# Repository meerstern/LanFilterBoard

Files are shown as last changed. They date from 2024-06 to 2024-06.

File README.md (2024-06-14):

# LANフィルタ基板
LAN Filter Board

## 概要
 * 本基板はLANノイズフィルタの評価基板です  
 * LAN機器やケーブルから放射、伝搬されるノイズ、エミッションを低減させます
 * EMC試験やエミッション、伝導妨害試験等の対策検討に便利です  
 * Ethernet 100/1000BASE-Tに対応した360Ω@100MHzのコモンモードフィルタを実装しています  
 * 4ペアのコモンモードフィルタを実装しています  

## 使用方法
 * LAN機器のLANケーブル間に本フィルタを挿入して使用します   
 * 本フィルタはストレート結線です
 * ストレート結線のLANケーブルを使用してください
 * 4つのフィルタは基板に実装されているため、ハンダ付け不要です  
 
## 使用時の注意点
 * 本基板はフィルタの評価目的です  
 * 本基板を最終的な機器に組み込むことは想定していません  
 * 本基板はノイズ源に近い箇所に接続してください  
 * PoE環境での仕様は想定していません  
 * 使用方法によっては意図せず通信品質低下やエミッションが増加する場合があります  
 * 評価の際は本基板のエミッションを考慮した上で十分にシールドした状態で確認してください  
 * フィルタを含む表面実装部品に大きな力や衝撃を与えないように注意してください
 * 大きな力や衝撃によってフィルタが破損する場合があります  

## 詳細
 * 使用部品は下記です  
 * 告知なしに実装部品を後継品もしくは同等品に変更する場合があります  

| 部品 | 型式 | 仕様 | 
|:---|:---|:---|
| Port | [1149868][1] | Max 10 GBit/s |
| Filter | [ALC2012-361-2P-T00][2] | 360Ω@100MHz,DC 0.5Ω, Typ.220mA, [Link][3] |

## 外観
  * サイズ 約51mm x約30mm x約22mm(コネクタ含む) 
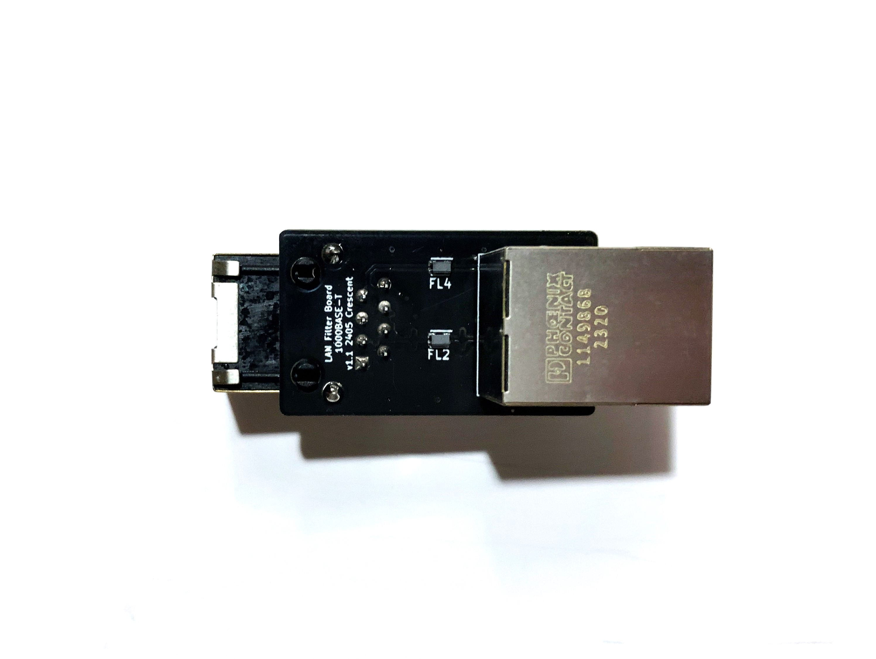
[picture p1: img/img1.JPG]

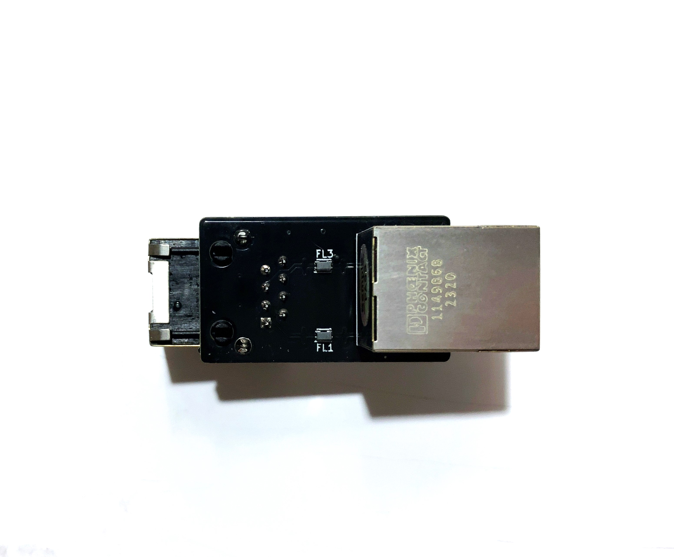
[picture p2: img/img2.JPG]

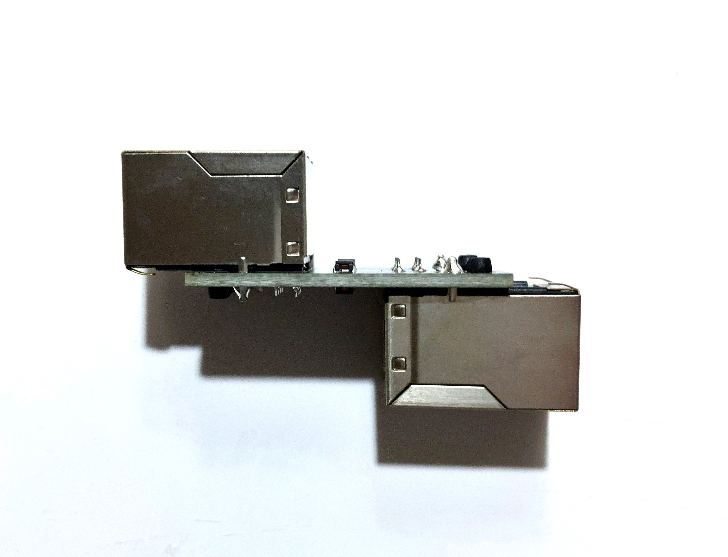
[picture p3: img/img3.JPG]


[1]: https://www.phoenixcontact.com/ja-jp/products/cuc-sp-j1st-a-r4lb-1149868
[2]: https://product.tdk.com/ja/search/emc/emc/cmf_cmc/info?part_no=ALC2012-361-2P-T00
[3]: https://product.tdk.com/ja/techlibrary/applicationnote/recommend_lan_cmf_cmc.html

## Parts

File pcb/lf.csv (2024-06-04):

ID | 参照記号 | パッケージ | 数 | 名称 | Supplier and ref
1 | FL4,FL3,FL2,FL1 | L_CommonModeChoke_Coilcraft_0805USB | 4 | EMI_Filter_CommonMode
2 | J2,J1 | 1149868 | 2 | 1149868

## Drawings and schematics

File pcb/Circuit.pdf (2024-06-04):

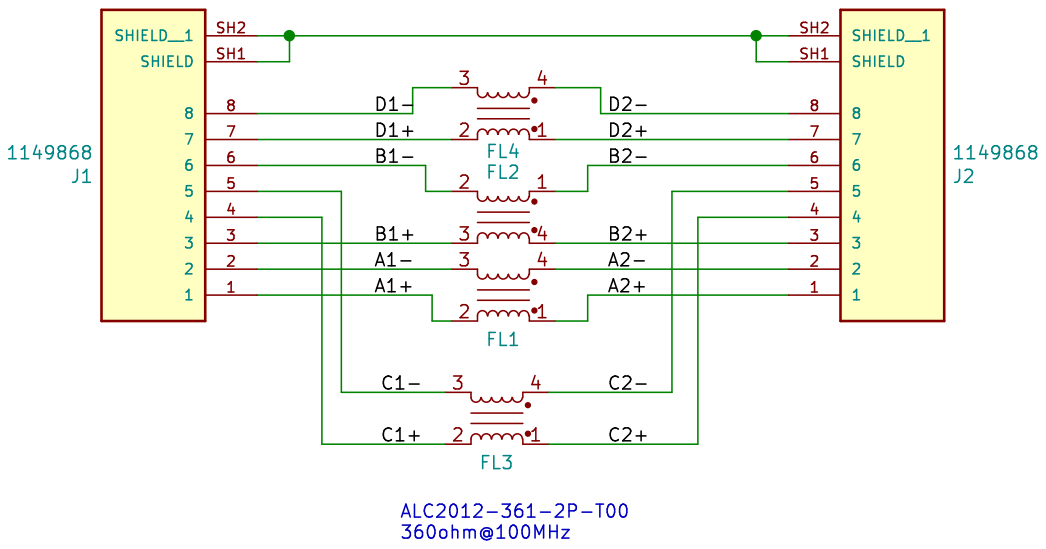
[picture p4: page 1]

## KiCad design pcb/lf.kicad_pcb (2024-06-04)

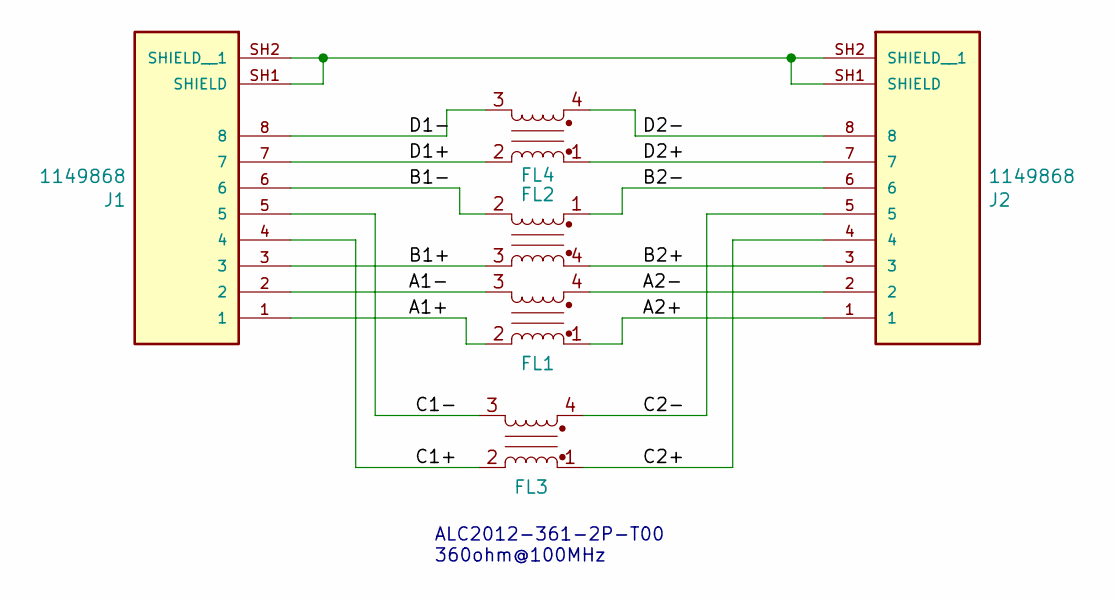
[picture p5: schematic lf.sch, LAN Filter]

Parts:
FL1, FL2, FL3, FL4: EMI_Filter_CommonMode; L_CommonModeChoke_Coilcraft_0805USB
J1, J2: 1149868; PARTREV 11.04.2022

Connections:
/A1+: FL1.2, J1.1
/A1-: FL1.3, J1.2
/A2+: FL1.1, J2.1
/A2-: FL1.4, J2.2
/B1+: FL2.3, J1.3
/B1-: FL2.2, J1.6
/B2+: FL2.4, J2.3
/B2-: FL2.1, J2.6
/C1+: FL3.2, J1.4
/C1-: FL3.3, J1.5
/C2+: FL3.1, J2.4
/C2-: FL3.4, J2.5
/D1+: FL4.2, J1.7
/D1-: FL4.3, J1.8
/D2+: FL4.1, J2.7
/D2-: FL4.4, J2.8
unnamed: J1.SH1 (SHIELD), J1.SH2 (SHIELD__1), J2.SH1 (SHIELD), J2.SH2 (SHIELD__1)

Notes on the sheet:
ALC2012-361-2P-T00 360ohm@100MHz

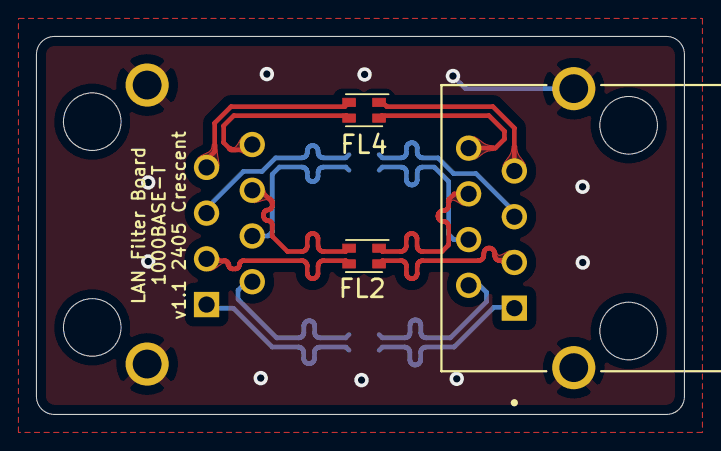
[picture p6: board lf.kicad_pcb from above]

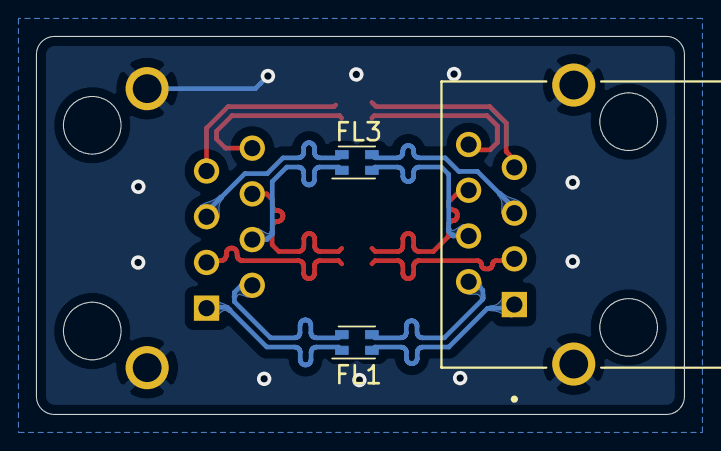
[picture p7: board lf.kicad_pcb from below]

Board: 2 copper layers, 36.0 x 21.0 mm, 6 parts (3 on the bottom side), 17 nets.
